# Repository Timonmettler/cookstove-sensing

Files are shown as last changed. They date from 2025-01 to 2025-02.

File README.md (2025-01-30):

<!-- badges: start -->

<!-- badges: end -->

<h1> Sensing improved cookstoves to estimate CO2 emission reduction </h1>

<b>Contributors</b>  
- Timon Mettler <a href="https://orcid.org/XXXX-XXXX-XXXX-XXXX">
ORCID logo XXXX-XXXX-XXXX-XXXX
</a> *author, developer*  
- Jakub Tkaczuk <a href="https://orcid.org/0000-0001-7997-9423">
ORCID logo 0000-0001-7997-9423
</a> *supervisor, maintainer*  
- Elizabeth Tilley <a href="https://orcid.org/0000-0002-2095-9724">
ORCID logo 0000-0002-2095-9724
</a> *supervisor*  

<p align="middle"> 

<br><br>
This repository compliments the openly-accessible bachelor's thesis, available on the<br \>  
<a href="">ETH Research Collection</a>.
</p>

# Background

This repository compliments the bachelor's thesis on developing the sensor system for estimating the emission reduction though improved cookstove usage. Hardware created within this project lays the foundations for establishing accurate and easy to operate hardware for obtaining carbon certificates under Paris Agreement. The thesis presents the design and implementation of a system for data collection and evaluation of the environmental impact of improved cookstoves compared to traditional models. The resulting system is open-source, reliable, and cost-effective. It uses Raspberry Pi Pico to collect data from a thermocouple and a scale to measure the runtime and wood consumption of cookstoves. Designed for deployment in remote areas lacking electricity and Wi-Fi connectivity, the system operates using solar panels and transmits sensor data to a cloud-based server via a cellular connection. By providing precise and reliable data, the system enhances the accuracy of emissions calculations associated with cookstoves. The work presented in the thesis and this repository serves as a comprehensive guide for creating a robust, cost-efficient, and remotely deployable data logging solution, contributing to the accurate assessment of CO2 emissions savings and supporting climate change mitigation efforts.

# Hardware

Hardware used in the project:
- Microcontroller (Raspberry Pi Pico) serves as the central processing unit to manage data acquisition and transmission.
- Micro SD card module and micro SD card allows storing the sensor data locally.
- SIM7670E Cellular modem enables reliable data transmission over cellular networks.
- Load cells and the HX711 load cell amplifier measure the weight of wood consumed by the cookstove.
- K-type thermocouple and AD8495 thermocouple amplifier measure cookstove temperature.
- PCF8523 Real-Time Clock provides accurate timestamps for collected data.
- Waveshare solar power management module (D) ensures continuous power supply by managing the batteries and solar panels.
- Three 18650 Li-ion batteries are selected for their energy density and reusability.
- Two 10 W, 12 V solar panels supply energy to charge the batteries in remote environments.
- LM3940 voltage regulator regulates the voltage from 5 V to 3.3 V to ensure safe operation.
- TRU COMPONENTS KST 220 enclosure provides a protective casing for the hardware.

| name | source | approximate price [CHF] |
| --- | --- | --- |
| Raspberry Pi Pico | [Pi-Shop](https://www.pi-shop.ch/raspberry-pi-pico-2) | 7.90 |
| Micro SD card module | | |
| Micro SD card | | |
| SIM7670E module | | |
| Three load cells | | |
| HX711 load cell amplifier | | |
| K-type thermocouple | | |
| AD8495 thermocouple amplifier | | |
| PCF8523 Real-Time Clock | | |
| Waveshare solar power management module (D) | | |
| Three 18650 Li-ion batteries | | | 
| Two 10 W, 12 V solar panels | | |
| LM3940 voltage regulator | | |
| TRU COMPONENTS KST 220 enclosure | | |
| **TOTAL** | | |

The dataflow between the hardware components is schematically represented below.

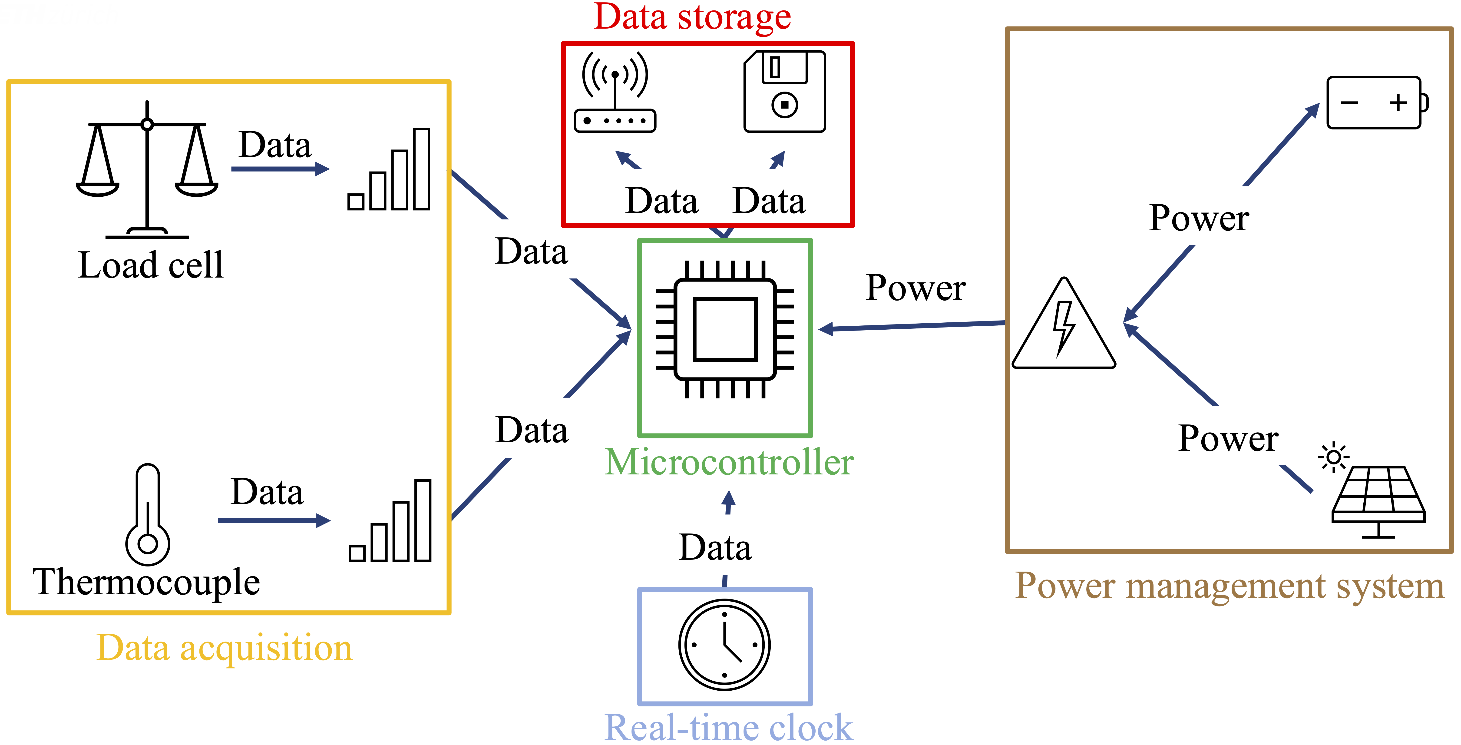
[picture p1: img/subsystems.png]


# Software

The `main.py` script follows the workflow presented on the figure below.

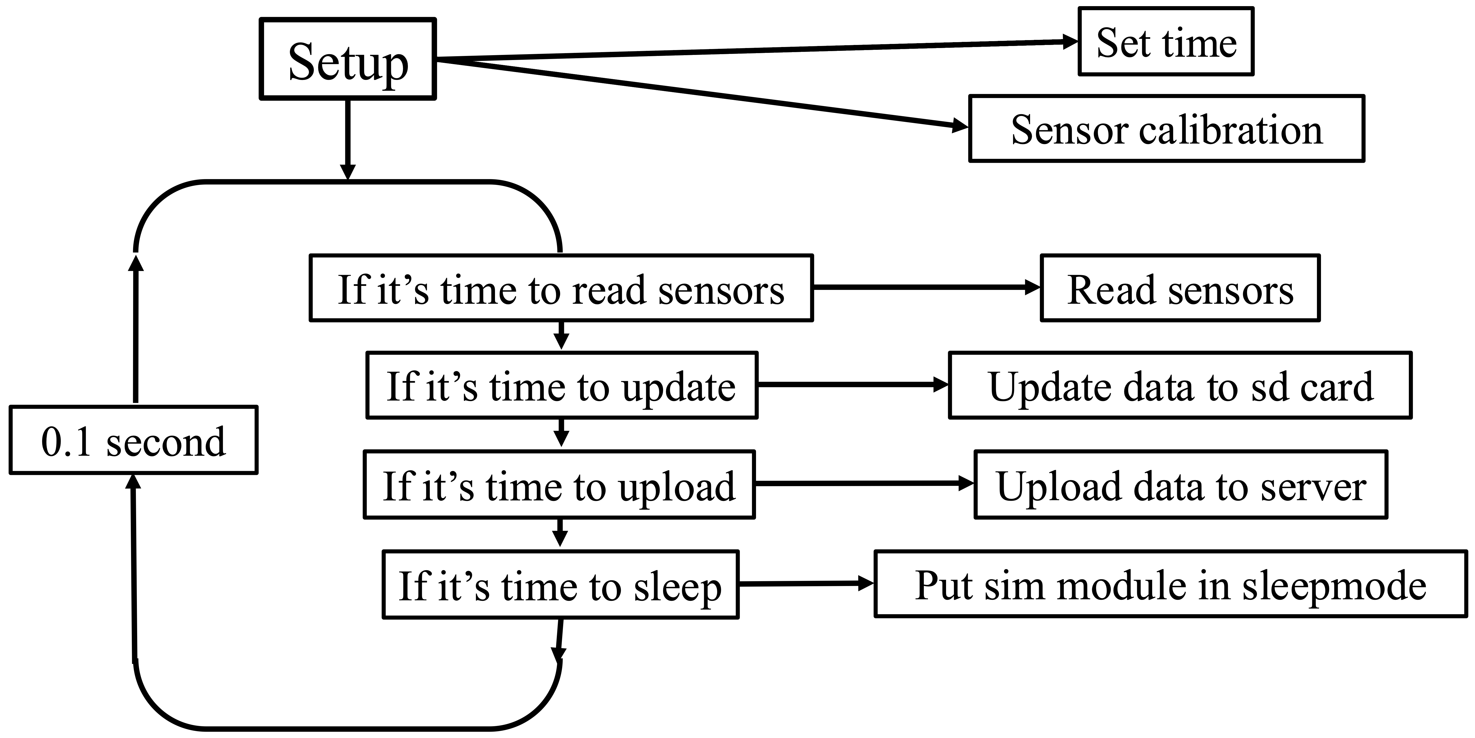
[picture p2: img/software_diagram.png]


# Wiring diagram

The wiring diagram presents electrical connections between hardware.

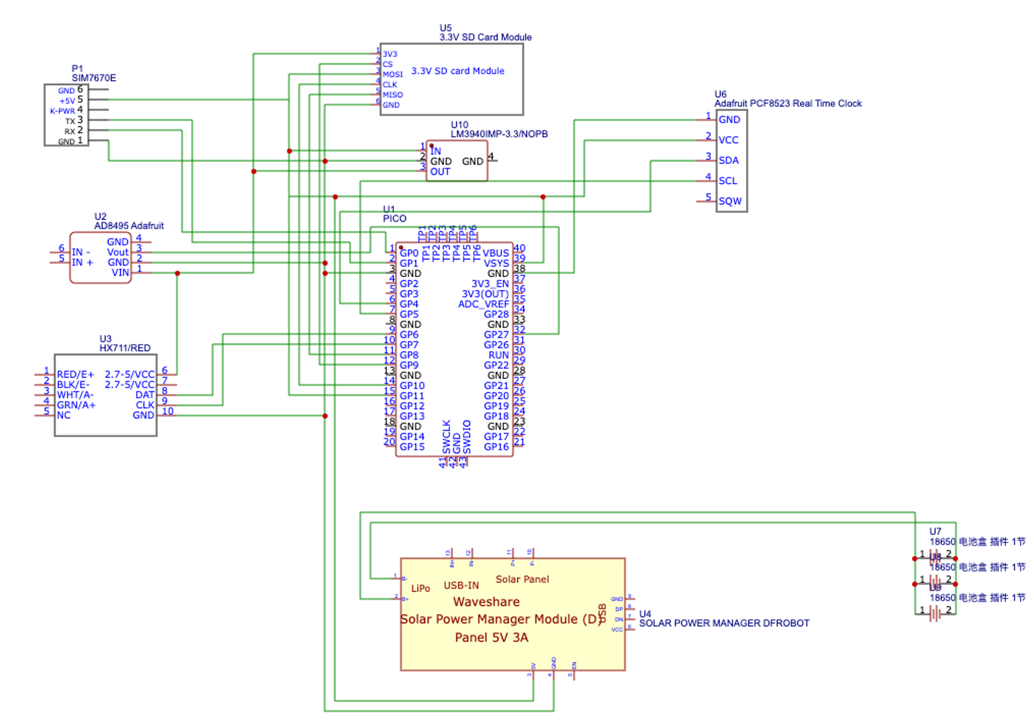
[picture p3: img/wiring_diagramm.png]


# License

Both the thesis, published on the [ETH Research Collection]() and the underlying data, published in this repository are licensed under [Creative Commons Attribution 4.0 International](https://github.com/Global-Health-Engineering/cookstove-sensing/blob/main/LICENSE.md).

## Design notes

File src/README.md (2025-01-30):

# `src`

`main.py` script contains the most up to date routines for running data acquisition and transfer from a scale and a thermocouple on Raspberry Pi Pico.

Before uploading `main.py` onto Raspberry Pi pico, update `APIkey` and `Channel` variables from your Thingspeak account. Then, load the main code and all the libraries to the Pi Pico.

`calibration_testing` directory contains scripts allowing to:
- calibrate the load cell
- set up the real time clock
- test thermocouples

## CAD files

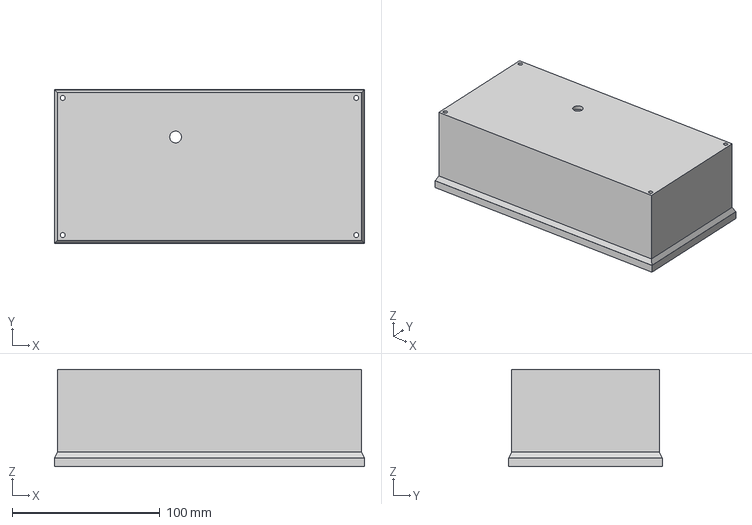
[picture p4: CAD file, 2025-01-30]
hardware/case/box.step
210.1 x 104.2 x 66.0 mm

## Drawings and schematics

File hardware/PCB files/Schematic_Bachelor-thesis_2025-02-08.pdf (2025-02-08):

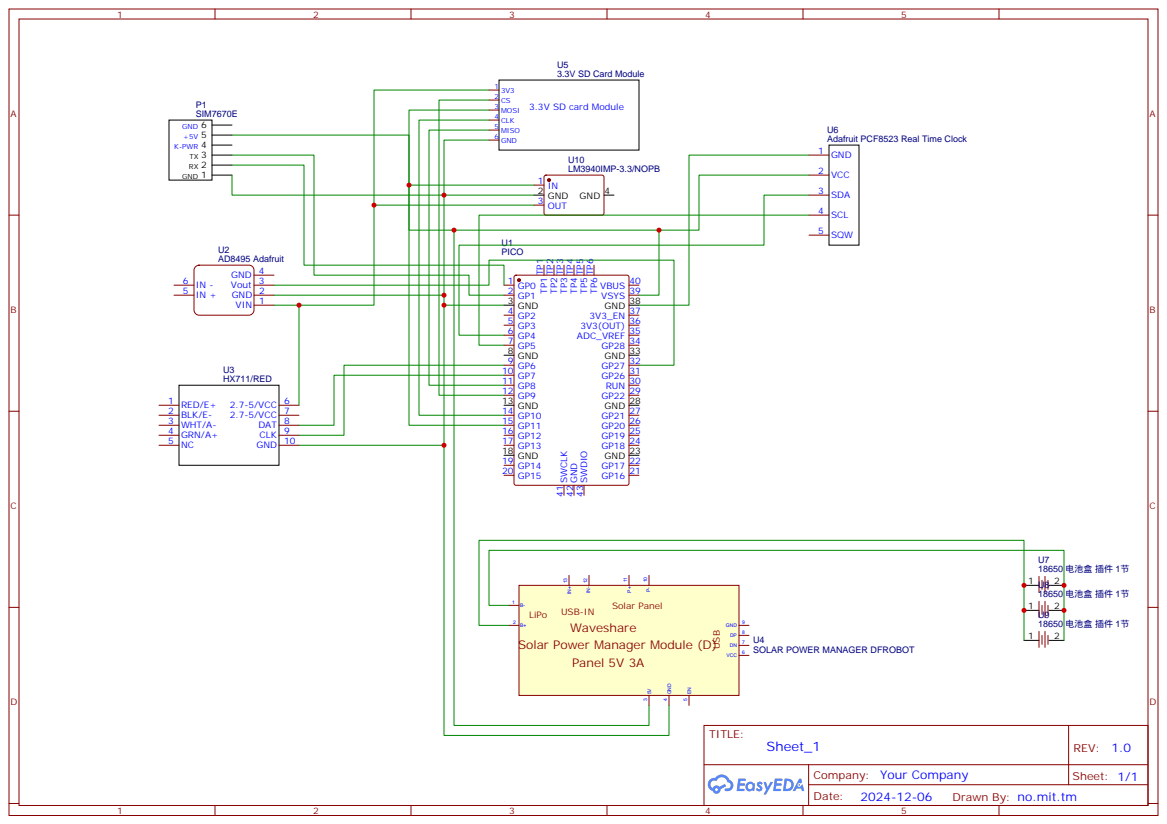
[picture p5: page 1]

USB-ININ⁻ ¹² IN⁺ ¹³

Drawn By: no.mit.tm

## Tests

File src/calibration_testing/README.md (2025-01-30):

# `src/calibration_testing`

This directory contains the following files, allowing to calibrate and test hardware:
- `calibrate_HX711.py` is used to get the raw values and calibration factor for the load cell.
- `set_RTC.py` is used to set the real time clock time using the connected computer time.
- `test_thermocouple.py` is used to test the thermocouple.

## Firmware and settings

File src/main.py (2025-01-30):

import machine
import sdcard
import uos
import json
import os
import requests
import time
import utime
import gc
import urtc
from hx711 import *

# enable garbage collector
gc.enable()

# turn on and off debugging, use: debug_print() for debugging
DEBUG = False

# blinking when uploading
blink = True

if blink:
    led = machine.Pin(25, machine.Pin.OUT)


########## Start RTC Setup ##########
i2c = machine.I2C(id = 0, scl=machine.Pin(5), sda=machine.Pin(4))
rtc = urtc.PCF8523(i2c)

# set pico RTC simmilar to external RTC
datetime = rtc.datetime()
system_rtc = machine.RTC()
system_rtc.datetime((
    datetime.year, datetime.month, datetime.day, 
    datetime.weekday, datetime.hour, datetime.minute, datetime.second, 0
))
########## End RTC Setup ##########


# variables
APIkey = "YOUR_PERSONNAL_API_KEY"                                                     ########## update personal APIkey                                                               ##########
Channel = "YOUR_CHANNEL_ID"                                                           ########## update Channel ID                                                                    ##########
updateperiod = 5                                                                      ########## update how often your sensors take samples                                           ##########
amount_samples = 10                                                                   ########## after how many samples do you want to save it to the SD card                         ##########
uploadperiod = 20                                                                     ########## update how often the data is uploaded to thinkspeak (lowest that is useful is 20sec) ##########
max_entries = 200                                                                     ########## adjust the max amount of entries in updates                                          ##########
url = "http://api.thingspeak.com/channels/"+ Channel +"/bulk_update.json"

data = {
    "write_api_key": APIkey,
    "updates": [
    ]
}

last_upload_day = None
update_counter = 0
collected_data = []
upload_state = 0  # Global state variable
last_upload_time = utime.time()  # Tracks the time of the last step
last_update_time = utime.time()
last_update_time_holder = utime.time()
upload_step_time = utime.time()
sleeping = False
upload_success = True


########## Start Loadcell Setup ##########
tare_value = 82277.0
calibration_factor = 4.276765e-05
hx = hx711(machine.Pin(6), machine.Pin(7))
hx.set_power(hx711.power.pwr_up)
hx.set_gain(hx711.gain.gain_128)
hx711.wait_settle(hx711.rate.rate_10)
########## End Loadcell Setup ##########


########## Start Thermocouple Setup ##########
# Create an ADC object on pin 26 (ADC0), which corresponds to physical pin 32 on the Pico
ad8495 = machine.ADC(26)
 
# Constants for calculations
VREF = 3.3  # Reference voltage for the Pico ADC
ADC_RESOLUTION = 65535  # 16-bit ADC resolution
########## End Thermocouple Setup ##########


########## Start SD Setup ##########
# Assign chip select (CS) pin (and start it high)
cs = machine.Pin(9, machine.Pin.OUT)

# Intialize SPI peripheral (start with 1 MHz)
spi = machine.SPI(1,
                  baudrate=1000000,
                  polarity=0,
                  phase=0,
                  bits=8,
                  firstbit=machine.SPI.MSB,
                  sck=machine.Pin(10),
                  mosi=machine.Pin(11),
                  miso=machine.Pin(8))

# Initialize SD card and change names of headers in the csv file
headers = ["Timestamp", "Weight[kg]", "Temperature"]
sd = sdcard.SDCard(spi, cs)

# Create a filename
basepath = "/sd/"
filename = "DAY"
ext = ".csv"
num = "0001"
collector = "collector"

# Mount filesystem
try:
    vfs = uos.VfsFat(sd)
    uos.mount(vfs, "/sd")
except Exception as e:
    print(f"SD Card error: {e}")
########## End SD Setup ##########


########## Start Sim7670E Setup ##########
# uart setting
uart_port = 0
uart_baute = 115200
Pico_SIM7670E = machine.UART(uart_port, uart_baute)
########## End Sim7670E Setup ##########


def send_at(cmd, back, timeout=7000):
    """ send AT command """
    answer = False
    # if nothing has been received for 100 ms, exit the while loop, stay max 7 sec there
    nothing_received = 100
    rec_buff = b''
    Pico_SIM7670E.write((cmd + '\r\n').encode())
    prvmills = utime.ticks_ms()
    while (utime.ticks_ms() - prvmills) < timeout and (not answer or (utime.ticks_ms() - prvmills) < nothing_received):
        if Pico_SIM7670E.any():
            rec_buff = b"".join([rec_buff, Pico_SIM7670E.read(1)])
            answer = True
            prvmills = utime.ticks_ms()
        time.sleep(0.02)
    
    if rec_buff != b'':
        answer = rec_buff.decode()
        print(cmd + ' back:' + answer)
        if "OK" in answer or "DOWNLOAD" in answer or "202 Accepted" in answer:
            return True
        print ("ERROR found")
        return False
    else:
        print(cmd + ' no responce')
        return False


def exists(filepath):
    """ checks if this file exists """
    try:
        f = open(filepath, "r")
        # continue with the file.
        return True
    except OSError:
       # handle the file open case
       return False


def createfile():
    """ create a file with a unique name """
    debug_print("1")
    global num, headers  # To modify the global `num` variable
    filepath = f"{basepath}{filename}{num}{collector}{ext}"
    while exists(filepath):
        num = f"{int(num) + 1 :04d}"  # Increment and format `num`
        filepath = f"{basepath}{filename}{num}{collector}{ext}"  # Update the filepath
        
    with open(f"{basepath}{filename}{num}{collector}{ext}", mode="w") as cfile:
        header_line = ",".join(headers) + "\n"
        cfile.write(header_line)  # Write the header row


def updatejson():
    debug_print("2")
    global last_update_time
    collector_filepath = f"{basepath}{filename}{num}{collector}{ext}"
    now = get_time()
    timestr = "{}-{}-{} {}:{}:{} +0100".format(now[0], now[1], now[2],now[3], now[4],now[5])
    last_update_time = utime.time()

    if now[5] != 59:
        incr = now[5] + 1
    else:
        incr = 0
    
    value1 = get_weight() # add sensor Values here
    value2 = get_temp()   # add sensor Values here
    
    new_entry = {
        "created_at": timestr,
        "field1": value1,
        "field2": value2
    }

    # Add the new entry to the "updates" list
    data["updates"].append(new_entry)
    
    append_to_csv_file([timestr, value1, value2])


def read_and_upload():
    debug_print("3")
    global data, upload_step_time # ensure the global `data` is accessible for updates
    
    # define the delay between commands (in seconds)
    delay = 0.5
    
    try:
        # get the current time
        current_time = utime.time()

        # check if it's time to move to the next step
        if current_time - upload_step_time >= delay:
            # initiate the upload process
            upload_step(json.dumps(data))
            upload_step_time = current_time
    except Exception as e:
        print(f"Unexpected error: {e}")


def upload_step(thinksdata):
    debug_print("4")
    global upload_state, data, last_upload_time, upload_step_time, last_upload_time_holder, sleeping, upload_success

    try:
        current_time = utime.time()
        if upload_state == 0:
            if not send_at("AT", "OK"):
                upload_success = False
                print(upload_success)
            last_upload_time_holder = current_time
        elif upload_state == 1:
            if not send_at("AT+CSQ", "OK"):
                upload_success = False
                print(upload_success)
        elif upload_state == 2:
            if not send_at("AT+COPS?", "OK"):
                upload_success = False
                print(upload_success)
        elif upload_state == 3:
            if not send_at("AT+CNMP=2", "OK"):
                upload_success = False
                print(upload_success)
        elif upload_state == 4:
            if not send_at("AT+CSCS=\"GSM\"", "OK"):
                upload_success = False
                print(upload_success)
        elif upload_state == 5:
            if not send_at("AT+CNSMOD?", "OK"):
                upload_success = False
                print(upload_success)
        elif upload_state == 6:
            if not send_at("AT+HTTPINIT", "OK"):
                upload_success = False
                print(upload_success)
        elif upload_state == 7:
            # attempt to upload data
            if not send_at(f"AT+HTTPPARA=\"URL\",\"{url}\"", 'OK'):
                upload_success = False
                print(upload_success)
        elif upload_state == 8:
            if not send_at("AT+HTTPPARA=\"CONTENT\",\"application/json\"", 'OK'):
                upload_success = False
                print(upload_success)
        elif upload_state == 9:
            if not send_at(f"AT+HTTPDATA={len(thinksdata)},1000", "OK"):
                upload_success = False
                print(upload_success)
            if not send_at(thinksdata, "OK"):
                upload_success = False
                print(upload_success)
        elif upload_state == 10:
            # post
            if not send_at("AT+HTTPACTION=1", 'OK'):
                upload_success = False
                print(upload_success)
        elif upload_state == 11:
            if not send_at("AT+HTTPHEAD", 'OK'):
                upload_success = False
                print(upload_success)
            else:
                upload_success = True
                if blink:
                    for i in range (10):
                        led.toggle()
                        time.sleep(0.2)
        elif upload_state == 12:
            if not send_at("AT+HTTPTERM", "OK"):
                upload_success = False
                print(upload_success)
            
            if upload_success:
                # reset state and clean up after successful upload
                upload_state = 0
                sleeping = False
                upload_success = True
                
                # Get the time the uploading process started
                last_upload_time = last_upload_time_holder
                
                #reset the json data
                data = {
                    "write_api_key": APIkey,
                    "updates": []
                }
                
                # collect garbage
                gc.collect()
                print("Upload sequence completed!")
                return # exit the function when done
            
            else:
                # Retry or handle failure
                gc.collect()
                upload_state = 0
                upload_success = True
                print("ES HET nöd funktioniert")
                print("Upload failed. Retrying...")
                return
            
        else:
            print("Invalid upload state encountered. Resetting...")
            upload_state = 0  # Reset state
            upload_success = True
            return

        # Move to the next state
        upload_state += 1

    except MemoryError:
        # Handle low-memory situations
        gc.collect()
        print("MemoryError: Garbage collection triggered.")

    except Exception as e:
        # Log unexpected errors for debugging
        print(f"Unexpected error in upload_step: {e}")
        upload_state = 0  # Reset state to avoid getting stuck


def sleepmode():
    global sleeping
    if send_at("AT+CSCLK=2", "OK"):
        sleeping = True
        print("Gute Nacht")


def get_weight():
    debug_print("5")
    for i in range (5):
        hx.get_value()
    weight_f = (hx.get_value() - tare_value) * calibration_factor
    return weight_f


def get_voltage(adc_pin):
    """ convert the ADC reading to voltage """
    debug_print("6")
    return (adc_pin.read_u16() * VREF) / ADC_RESOLUTION


def get_temp():
    debug_print("7")
    temperature_c = 0
    for i in range (5):
        temperature_c += (get_voltage(ad8495) - 1.25) / 0.005
    return temperature_c/5


def get_time():
    debug_print("8")
    datetime = rtc.datetime()
    return datetime.year, datetime.month, datetime.day, datetime.hour, datetime.minute, datetime.second, datetime.weekday, 335


def debug_print(*args):
    """ print debug messages if debugging is enabled """
    global DEBUG
    if DEBUG:
        print(*args)


def append_to_csv_file(data_row):
    """
    Append a single row of data to an existing CSV file.
    :param data_row: List of data entries corresponding to the headers.
    """
    global amount_samples, update_counter, collected_data
    # Add the new data row to the collection
    collected_data.append(data_row)
    print(f"Appended to data collection: {data_row}")
    update_counter += 1
    
    # Write to the CSV file when enough samples are collected
    if update_counter >= amount_samples:
        with open(f"{basepath}{filename}{num}{collector}{ext}", mode="a") as cfile:
            # Write each collected row as a line in the CSV file
            for row in collected_data:
                data_line = ",".join(map(str, row)) + "\n"  # Add newline character
                cfile.write(data_line)
        print(f"Appended to CSV: {collected_data}")
        
        # Reset collection and counter
        collected_data = []  # Clear collected data after writing
        update_counter = 0


def main():
    while True:
        try:
            current_time_mainloop = utime.time()
            
            #create a new json file every day
            now = get_time()
            current_day = (now[0], now[1], now[2])
            if current_day != last_upload_day:
                append_to_csv_file([])
                createfile()
                last_upload_day = current_day
            
            # check if we need to update the JSON file
            if current_time_mainloop - last_update_time >= updateperiod:
                updatejson()
            
            # check if we want to upload the json file
            if current_time_mainloop - last_upload_time >= uploadperiod:
                read_and_upload()
            
            if not sleeping:
                sleepmode()
            
            #Limit the size of the "updates" List
            entries_updates = data.get("updates", [])
            if len(entries_updates) > max_entries:
                del entries_updates[:len(entries_updates) - max_entries]
        
        except MemoryError:
            # Handle low-memory situations
            gc.collect()
            print("MemoryError: Garbage collection triggered.")
        
        except Exception as e:
            # Log unexpected errors for debugging
            gc.collect()
            print(f"Unexpected error: {e}")

        # Add a short sleep to prevent tight looping
        time.sleep(0.1)


if __name__ == "__main__":
    main()

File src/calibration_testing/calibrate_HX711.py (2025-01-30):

import machine
from hx711 import *

print("calibration started")
tare_value = -33476.7
calibration_factor = 2.508349e-05
hx = hx711(machine.Pin(6), machine.Pin(7))
hx.set_power(hx711.power.pwr_up)
hx.set_gain(hx711.gain.gain_128)
hx711.wait_settle(hx711.rate.rate_10)
estimator = 0


def calibrate():
    global tare_value, calibration_factor, estimator
    print("place the scale in its unloaded state.")
    
    while input("press Enter to continue...") != "":
        print("just press Enter when you're ready (don't type anything)!")
    
    
    for i in range (10): # to clear hx values
        hx.get_value()
    
    for i in range (10): # get values
        estimator = estimator + hx.get_value()

    tare_value = estimator / 10
    
    print(f"tare value: {tare_value}")
    
    print(f"place a known weight on the scale.")
    time.sleep(2)
    weight = float(input("type in the weight"))
    
    for i in range (10): # to clear hx values
        hx.get_value()
    
    estimator = 0
    
    for i in range (10): #get values
        estimator = estimator + hx.get_value()
    
    raw_value_with_weight = estimator / 10
    print(f"raw value with weight: {raw_value_with_weight}")
    
    # Calculate calibration factor
    calibration_factor = weight / (raw_value_with_weight - tare_value)
    print(f"calibration factor: {calibration_factor}")


def main():
    calibrate()

    while True:
        for i in range (5):
            hx.get_value()
        weight = (hx.get_value() - tare_value) * calibration_factor
        
        print(weight)
        time.sleep(2)


if __name__ == "__main__":
    main()

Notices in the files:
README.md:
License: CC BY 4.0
